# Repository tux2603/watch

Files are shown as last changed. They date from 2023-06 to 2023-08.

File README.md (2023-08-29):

# Binary Watch

_revision 2.0_

A 12 hour wrist watch that displays the current time in BCD using LEDs. The watch is powered by a single CR2032 coin cell and uses an ATtiny402 microcontroller to keep track of time and drive the LEDs. The time can be viewed or set at any time by pressing the two buttons on the face of the watch.

PCB fabrication for this project was sponsered by [PCBWay](https://www.pcbway.com/), and I would like to thank them for their support! I was very happy with the quality of the PCBs they sent me, and their staff was very easy to work with.

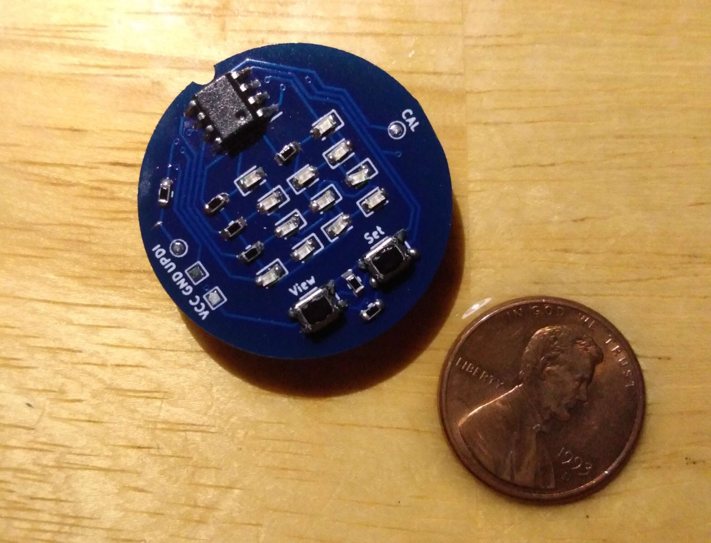
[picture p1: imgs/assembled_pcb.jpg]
Assembled PCB


_Fully assembled PCB, supplied by PCBWay and hand assembled by me. US penny for scale_

## Instructions

### Viewing the time

To view the time, simply press the `VIEW` button on the face of the watch. This will automatically wake the microcontroller and display the current time for 10 seconds. After 10 seconds, the LEDs will be turned off and the microcontroller will go back to sleep, conserving battery life.

### Setting the time

To set the time, first wake the watch from sleep by pressing the `VIEW` button. Once the watch is awake, press the `SET` button. The watch will now be in time setting mode, and the digit that is currently selected will flash once every two seconds. To change the value of the currently selected digit, press the `VIEW` button. Once the desired value is entered, press the `SET` button again to select the next digit and repeat until all digits are set. Once all digits are set, the watch will automatically return to view mode and go back to sleep after 10 seconds.

### Resetting the watch

To reset the watch, first wake the watch from sleep by pressing the `VIEW` button. Once the watch is awake, press and hold either button for at least three seconds. The watch will save the currently set time before resetting and will automatically return to view mode after the reset is complete.

## Design

Some trickery was needed to drive twelve LEDs and read two push buttons with the limited number of GPIO pins available. The LEDs are arranged in a [charlieplexing matrix](https://en.wikipedia.org/wiki/Charlieplexing), allowing all twelve LEDs to be controlled with just four tri-state GPIO pins. The push buttons are then read using a small resistor ladder with a single GPIO pin. Pressing the `VIEW` button will pull the voltage on the pin to `GND`, and pressing the `SET` button will pull the voltage on the pin to `0.5 * Vdd`. If no button is pressed, the voltage on the pin is pulled to `Vdd`. This way, only five GPIO pins are used and `PA0` is left to function solely as the UPDI pin, allowing for easy programming of the ATtiny402.

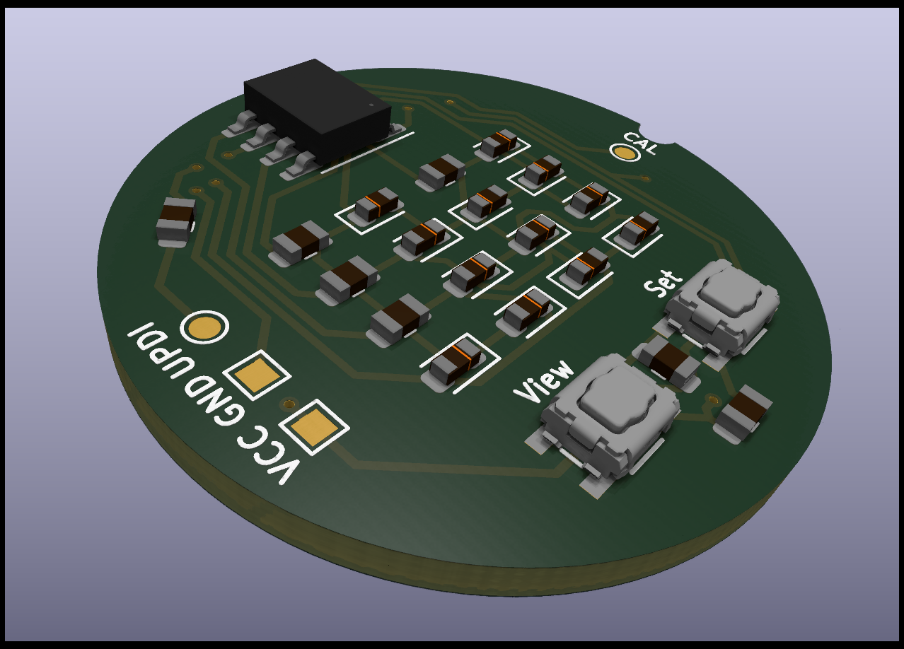
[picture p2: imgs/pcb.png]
PCB Render


### Electronics BOM

| Description | Count | Manufacturer Part Number | DigiKey Part Number  | Substitutions |
| --- | ----- | --- | --- | --- |
| CR2032 coin cell holder | 1 | BAT-HLD-001-TR | BAT-HLD-001-TRCT-ND  | Substitutions are possible, but will require traces to be re-routed |
| Blue LED | 12 | IN-S63BT5B | 1830-1068-1-ND | Any other 0603 LED can be used, but if a different color is used the color will be different |
| 47Ω 1/8W Resistor | 4 | ERJ-H3GJ470V | 10-ERJ-H3GJ470VCT-ND | Any 0603, 47Ω resistor with a power rating of 1/8W or higher |
| 4.7kΩ 1/8W Resistor | 1 | ERJ-H3GJ472V | 10-ERJ-H3GJ472VCT-ND | Any 0603, 4.7kΩ resistor with a power rating of 1/8W or higher |
| 10kΩ 1/8W Resistor | 2 | ERJ-H3GJ103V | 10-ERJ-H3GJ103VCT-ND | Any 0603, 4.7kΩ resistor with a power rating of 1/8W or higher |
| Momentary switch | 2 | EVP-AA202K | P13348SCT-ND | Substitutions are possible, but will require traces to be re-routed |
| ATtiny 402 microcontroller | 1 | ATTINY402-SSNR | ATTINY402-SSNRCT-ND  | Any ATtiny402. The ATtiny202 should also work, but has less flash and has not been tested. |

### Mechanical BOM

| Description | Count | Source |
| --- | ----- | --- |
| Watch Body | 1 | [CAD file](cad/watch-body.step) |
| Watch Back | 1 | [CAD file](cad/watch-back.step) |
| PCB | 1 | [Gerber files](pcb/gerbers.zip) |
| CR2032 coin cell | 1 | Your favorite source for watch batteries |
| 18mm watch band  | 1 | Your favorite source for watch bands |

## Assembly

### PCB

Unless you're lucky enough to have PCB fabrication facilities in house, you'll need to send the Gerber files to a third-party manufacturer for fabrication. I used DKRed for my initial prototypes, but after releasing v1 [PCBWay](https://www.pcbway.com/) reached out to me and offered to sponsor PCB fabrication for v2. Since I had selected tolerances to work with all of the major PCB fabrication services, I was more than happy to accept their offer. Having worked with both DKRed's ENIG finish and PCBWay's HASL finish, I would definietly have to say I preffered PCBWay's HASL for hand-soldering. The HASL finish made the soldering process a little bit easier, which when you're hand soldering small SMD components is always appreciated.

The components for the watch were picked to make hand soldering possible with a decent soldering iron and a steady hand, but it should also be possible to use a reflow oven or hot plate to solder the components on the face of the PCB. The battery holder will still likely need to be soldered by hand though, but it's nice and big so it shouldn't be too difficult. For hand soldering, I used the following procedure:

1.  Solder the LEDs and 47Ω resistors to the middle section of the PCB.

    - The resistors go in the spots with the two parallel silk screen lines (1, 3, 5, and 9 in Figure 1). These resistors aren't polarized, so they can be soldered in any orientation.
    - The LEDs go in the spots with the C-shaped silk screen lines around them (2, 4, 6, 7, 8, 10, 11, 12, 13, 14, 15, and 16 in Figure 1). The LEDs are polarized, so make sure to solder them in the correct orientation. If you use the LEDs specified in the BOM, the cathode will be marked with a tiny green dot. This green dot should be facing towards the C-shaped silk screen line. This orientation is also shown in Figure 1.

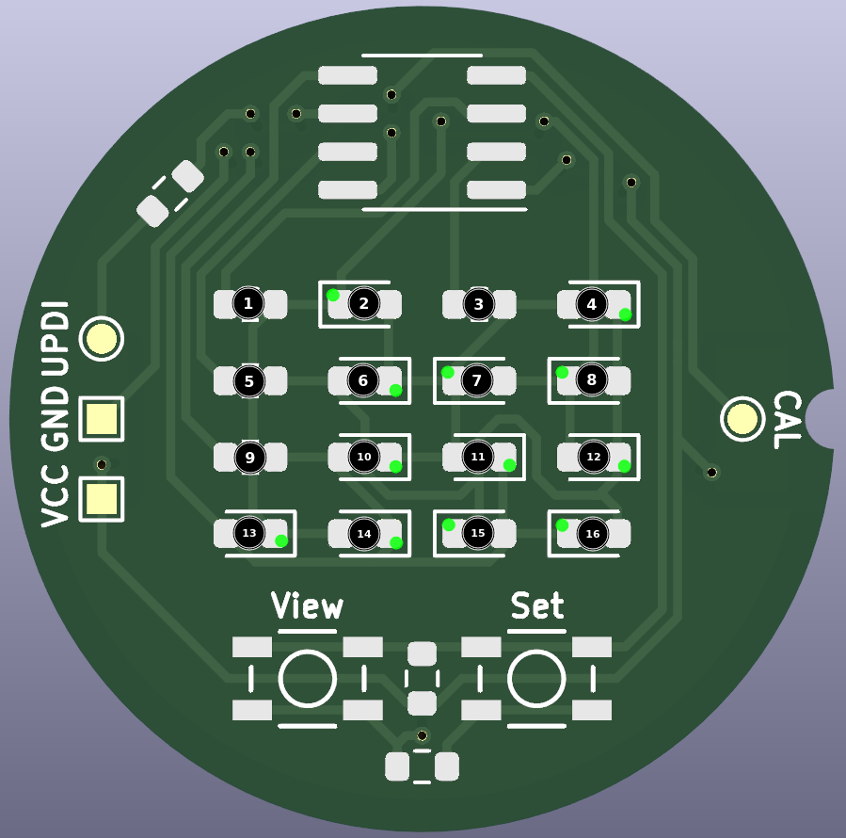
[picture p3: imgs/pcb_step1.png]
LED and resistor placement
    

    _Figure 1_: LED and resistor placement

2.  Verify that the resistors and LEDs were placed correctly

    - Apply the positive and negative connections to a 3.3V source to the pads shown in Figure 2 using the table below. If everything is soldered correctly, the corresponding

    | LED | Positive pad | Negative pad |
    | --- | ------------ | ------------ |
    | 2   | 1            | 2            |
    | 4   | 1            | 3            |
    | 6   | 3            | 1            |
    | 7   | 2            | 1            |
    | 8   | 3            | 2            |
    | 10  | 4            | 1            |
    | 11  | 1            | 4            |
    | 12  | 2            | 3            |
    | 13  | 4            | 2            |
    | 14  | 2            | 4            |
    | 15  | 4            | 3            |
    | 16  | 3            | 4            |

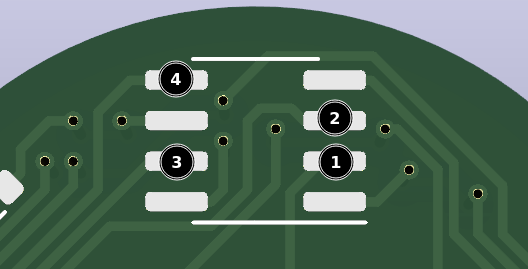
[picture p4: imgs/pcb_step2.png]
LED test pads
    

    _Figure 2_: LED test pads

3.  Solder the 4.7kΩ an 10kΩ resistors to the PCB

    - The 4.7kΩ resistor and two 10kΩ resistors go in the remaining spots with the two parallel silk screen lines (1, 2, and 3 in Figure 3). These resistors aren't polarized, so they can be soldered in any orientation.
      - The 4.7kΩ resistor goes in the spot with the two parallel silk screen lines in the upper-left corner of the PCB (1 in Figure 3)
      - The two 10kΩ resistors go in the spots with the two parallel silk screen lines in bottom center of the PCB (2 and 3 in Figure 3)

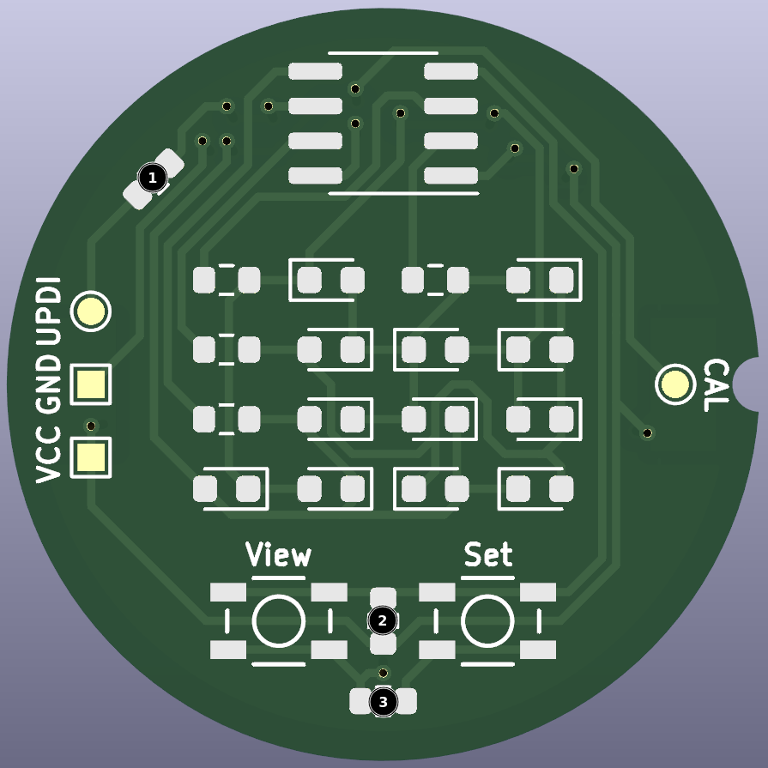
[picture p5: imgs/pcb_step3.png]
remaining resistor placement
    

    _Figure 3_: Remaining resistor placement

4.  Solder the buttons to the PCB

    - The buttons go above the silk screen labels reading `SW1` and `SW2`. The buttons aren't polarized, so they can be soldered in either direction

5.  Solder the ATtiny402 to the PCB

    - The ATtiny402 goes in the remaining spot on the front of the PCB with the small dimple or notch in the chip facing the center of the PCB

6.  Solder the battery holder to the PCB

    - Flip the PCB over and solder the battery holder to the four pads on the back

### Flashing

Three solder pads, labeled VCC, GND, and UPDI, are supplied on the watch face to allow for simple programming of the ATtiny using a UPDI programmer. Any UPDI programmer should work, but I used an Arduino Uno running [jtag2updi](https://github.com/ElTangas/jtag2updi/). The 4.7k series resistor required for flashing is already included on the PCB, so no external resistor is necessary.

1. Connect the VCC, GND, and UPDI solder pads to the corresponding pins using jumper wires. These jumper wires can be soldered or clipped on, it doesn't really matter. Note that the pads and traces are very small and fragile, so be careful not to put too much stress on them or they could rip off of the PCB.

   - The VCC pad should be connected to the 5V pin on the Arduino
   - The GND pad should be connected to the GND pin on the Arduino
   - The UPDI pad should be connected to the D6 on the Arduino

2. Hook the Arduino up to your PC and note what port it is connected to (eg, COM3, /dev/ttyACM0, /dev/ttyUSB0, etc). Set the `PORT` variable on line four of the [Makefile](Makefile) to this value, replacing the default value of `/dev/ttyACM0`

3. Run `make flash` to flash the watch. Alternatively, you can manually run the command `avrdude -c jtag2updi -P <YOUR_PORT> -p attiny402 -U flash:w:bin/main.hex -U eeprom:w:bin/eeprom.hex` to flash the watch.

4. The watch should automatically enter calibration mode after flashing. If you don't want to calibrate the watch right now, just hold down the `VIEW` button for at least three seconds to reset the watch.

### Calibration

After flashing the firmware, the watch will automatically enter one-time calibration mode. In this mode the watch will generate a square wave on the `CAL` solder pad, which can be measured using an oscilloscope. The period of this waveform should be as close to 468.75ms as possible, but it will initially be a good deal off from this value. To calibrate the watch, follow these steps:

1. Connect the `CAL` solder pad to the positive terminal of an oscilloscope probe using a jumper wire. Connect the negative terminal of the probe to the `GND` solder pad.
2. Measure the period of the generated square wave and compare it to the desired value of 468.75ms.
   - If the measured period is to high, press the `VIEW` button to decrease the period.
   - If the measured period is to low, press the `SET` button to increase the period.
3. Repeat step 2 thirteen times. After the last repetition, the watch will automatically save the calibration value and restart into standard operation mode.

To prevent accidental re-calibration, the watch will only enter calibration mode immediately after flashing by default. If you want to enable entering calibration mode without flashing the watch, write the value `0x01` to EEPROM address `0x05`. This will allow the watch to enter calibration mode by holding down the `SET` button for at least three seconds. To disable this feature again, write the value `0x00` to EEPROM address `0x05`.

## Customization

The functionality of the watch can be customized by modifying, compiling, and flashing the [source code](src/main.c). For simple changes, the following configuration options can be modified in the [config.h](src/config.h) file:

| Option | Description | Default Value | Recommended Range | Units |
| --- | --- | --- | --- | --- |
| `BLINK_FREQUENCY`  | The frequency at which the currently selected digit will blink while in time setting mode | 1 | 0.25 - 2 | Hz |
| `DEBOUNCE_COUNT` | The number of consecutive update cycles that a button state must be stable before it is considered to be pressed | 50 | 5 - 500 | update cycles |
| `RESET_HOLD_TIME`  | The number of seconds that a button must be held before the watch is reset | 3 | 1 - 10 | s |
| `SLEEP_TIMEOUT` | The number of seconds that the watch will remain awake before automatically going back to sleep | 10 | 1 - 60 | s |
| `UPDATE_FREQUENCY` | The frequency at which the LED matrix is updated and input is read from the buttons. | 480 | 96 - 5000 | Hz |

To compile the code, the avr-gcc tool chain will need to be installed with support for the ATtiny402

## License

This work is licensed under a [Creative Commons Attribution-NonCommercial 4.0 International License](https://creativecommons.org/licenses/by-nc/4.0). You are free to share, use, and modify this work for any non-commercial reasons as long as you give appropriate credit. The author grants permission for PCB and CAD design files to be sent to third-party manufacturers for fabrication as long as these fabricated parts or assemblies containing these fabricated parts are not later resold for profit.

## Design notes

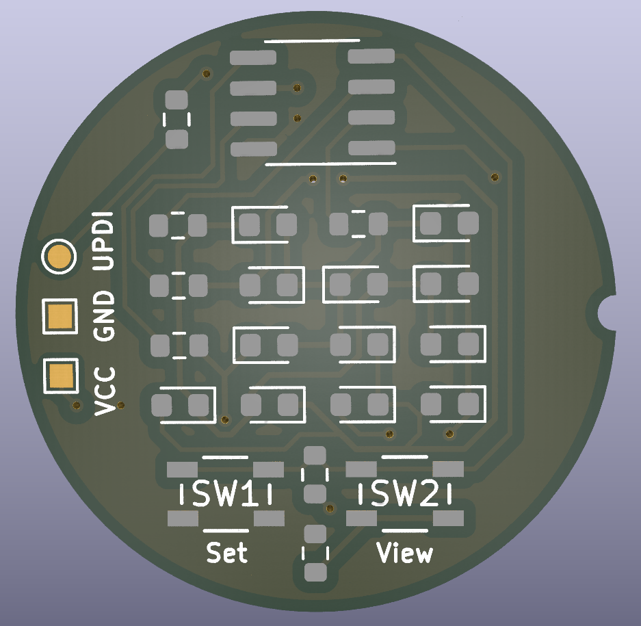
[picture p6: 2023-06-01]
imgs/pcb_front.png

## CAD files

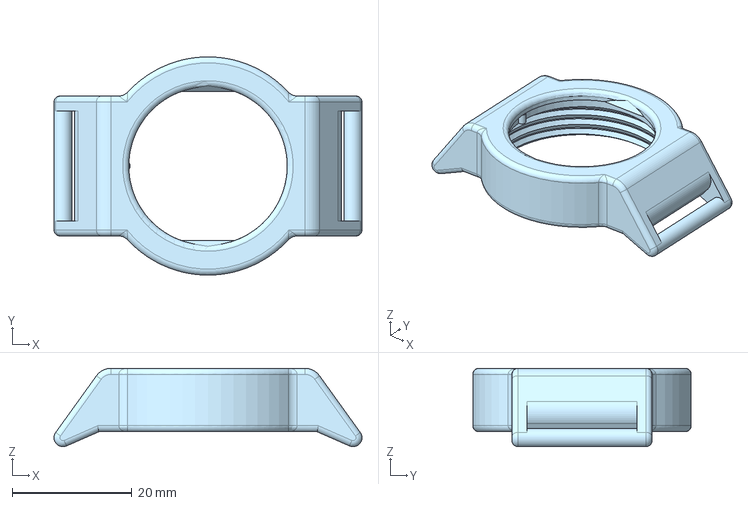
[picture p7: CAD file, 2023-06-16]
cad/watch_body.step
51.5 x 36.5 x 13.1 mm

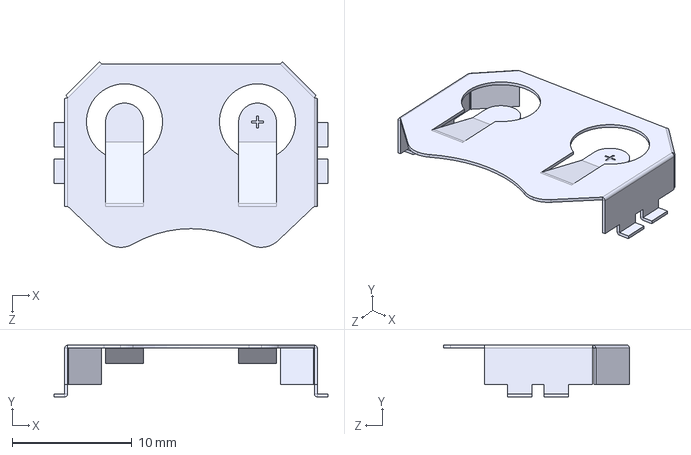
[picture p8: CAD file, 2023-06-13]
pcb/component_models/BAT-HLD-001-TR.step
22.9 x 4.32 x 15.5 mm

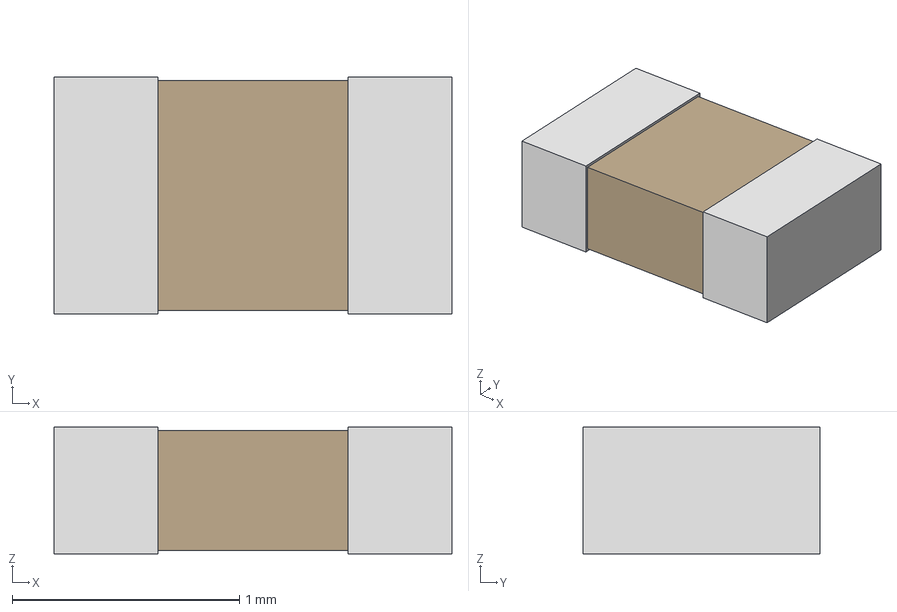
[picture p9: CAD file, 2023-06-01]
pcb/component_models/ERJ-H3GJ470V.step
1.75 x 1.04 x 0.559 mm

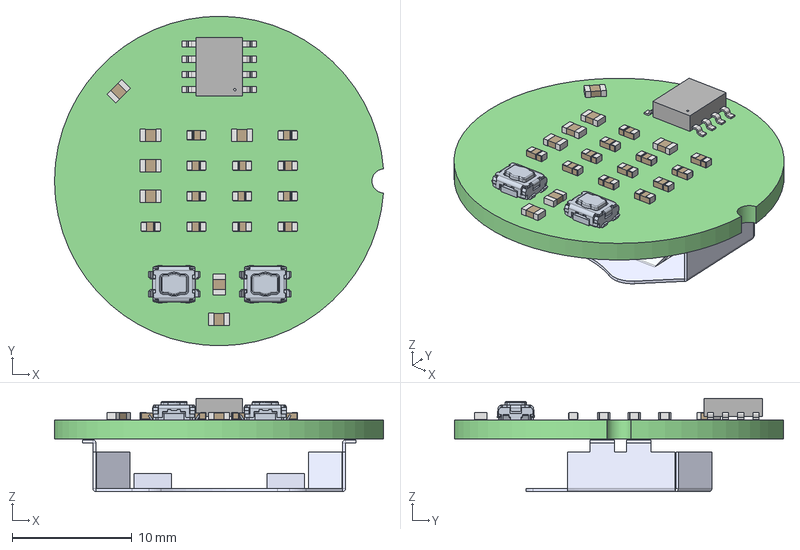
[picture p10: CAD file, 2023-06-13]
cad/pcb.step
27.5 x 27.5 x 7.77 mm
watch PCB

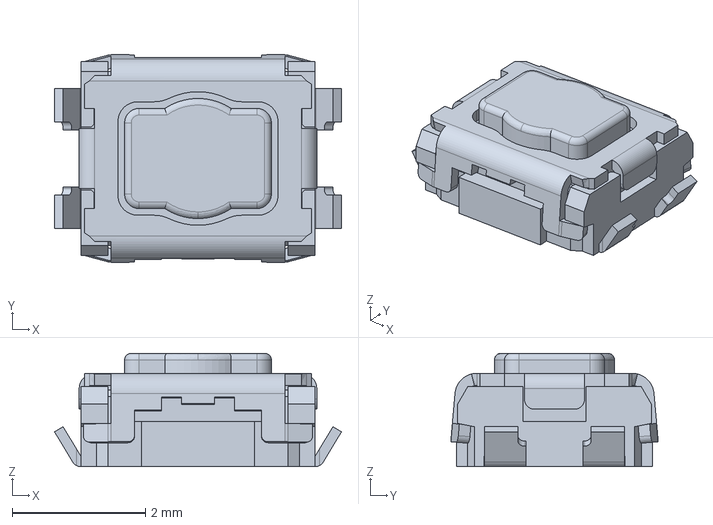
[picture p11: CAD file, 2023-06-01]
pcb/component_models/evpaa202k.step
4.30 x 3.11 x 1.70 mm

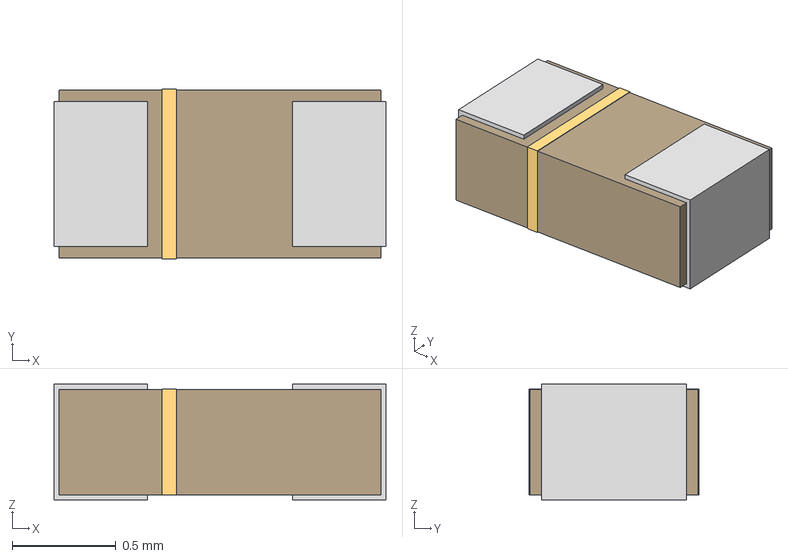
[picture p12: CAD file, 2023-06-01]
pcb/component_models/IN-S63BT.step
1.60 x 0.818 x 0.559 mm

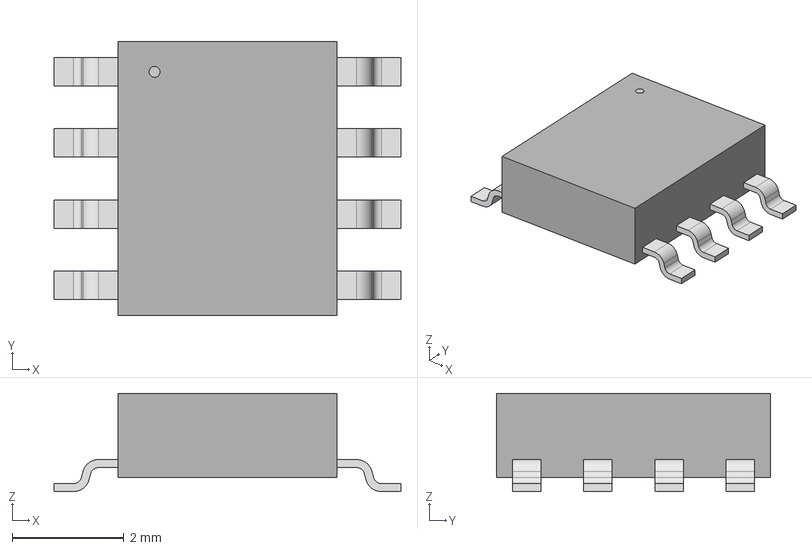
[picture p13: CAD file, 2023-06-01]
pcb/component_models/ATTINY402-SSNR.step
6.20 x 4.90 x 1.75 mm

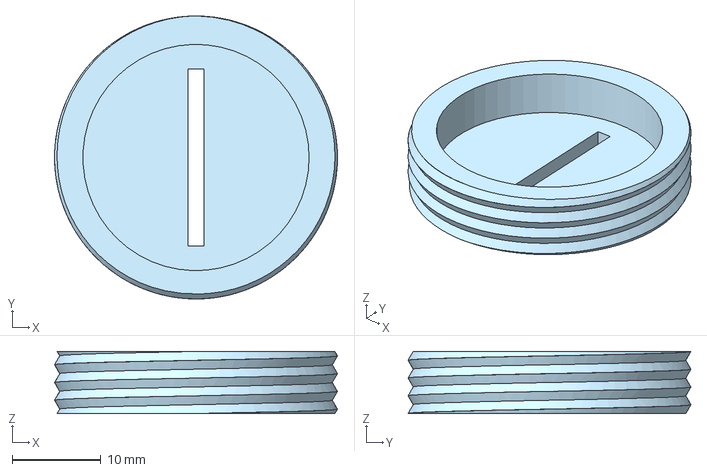
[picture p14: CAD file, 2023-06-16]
cad/watch_screw.step
31.9 x 31.9 x 7.00 mm

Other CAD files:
pcb/component_models/ERJ-H3GJ472V.step

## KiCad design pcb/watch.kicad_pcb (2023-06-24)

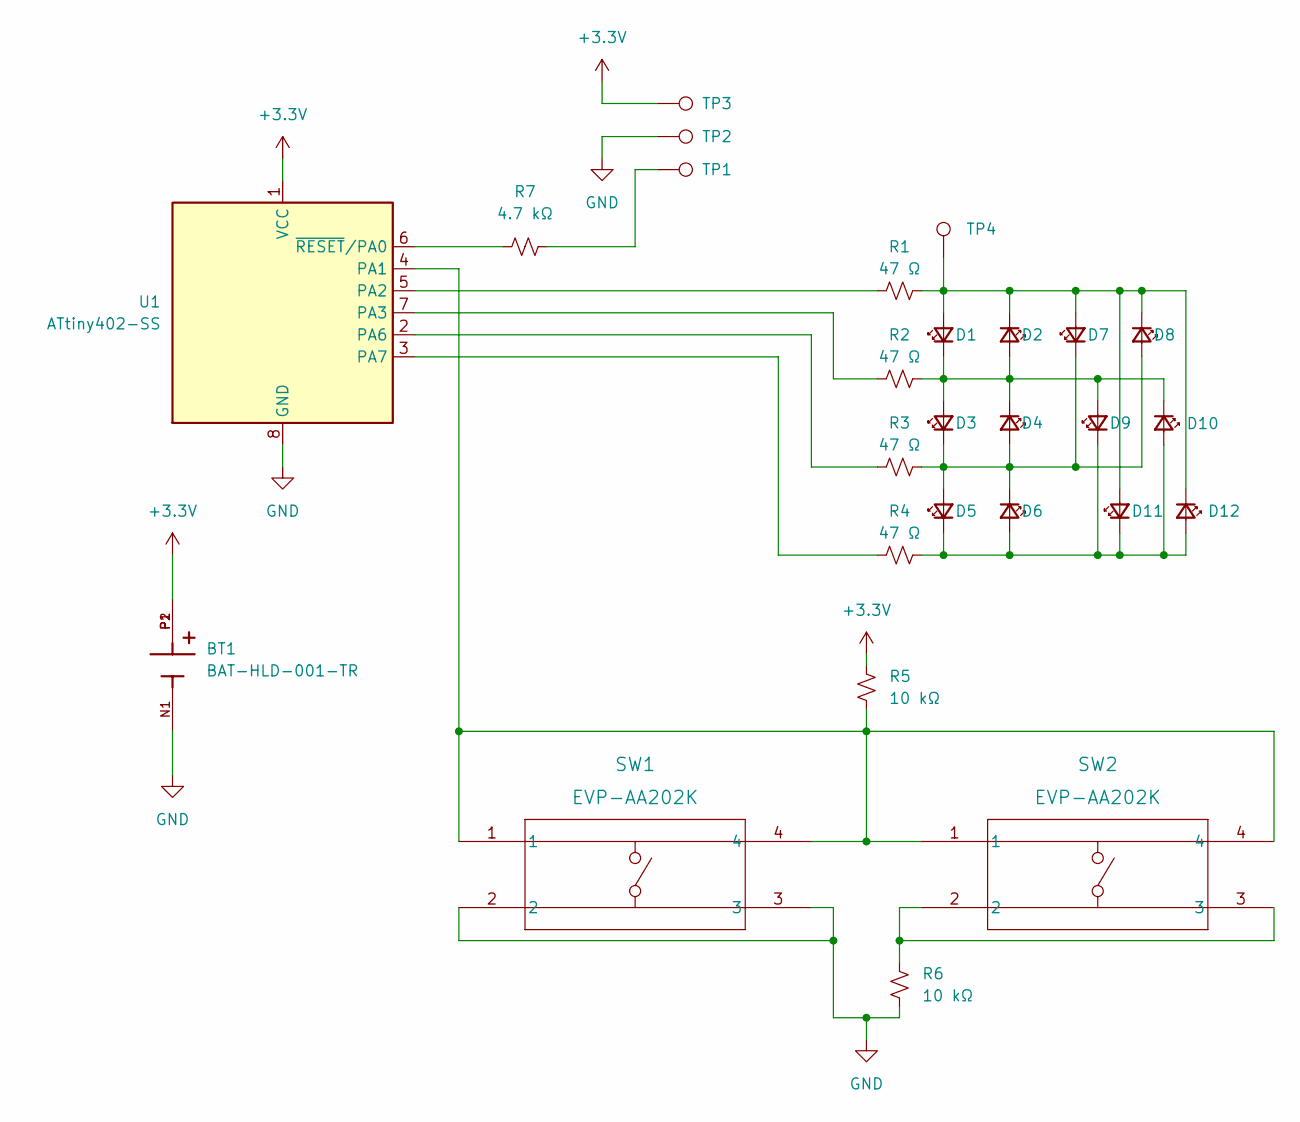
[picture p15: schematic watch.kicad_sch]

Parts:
BT1: BAT-HLD-001-TR; BAT_BAT-HLD-001-TR; PARTREV B
D1, D2, D3, D4, D5, D6, D7, D8, D9, D10, D11, D12: LED_Small; LED_0603_1608Metric
R1, R2, R3, R4: 47 Ω; R_0603_1608Metric
R5, R6: 10 kΩ; R_0603_1608Metric
R7: 4.7 kΩ; R_0603_1608Metric
SW1, SW2: EVP-AA202K; SW_EVP-AA102K_PAN
TP1, TP4: TestPoint; TestPoint_Pad_D1.0mm
TP2, TP3: TestPoint; TestPoint_Pad_1.0x1.0mm
U1: ATtiny402-SS; SOIC-8_3.9x4.9mm_P1.27mm

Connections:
+3.3V: BT1.P1, BT1.P2, R5.1, TP3.1, U1.1 (VCC)
GND: BT1.N1, R6.2, SW1.2, SW1.3, TP2.1, U1.8 (GND)
unnamed: D1.1 (K), D2.2 (A), D3.2 (A), D4.1 (K), D9.2 (A), D10.1 (K), R2.2
unnamed: D1.2 (A), D2.1 (K), D7.2 (A), D8.1 (K), D11.2 (A), D12.1 (K), R1.2, TP4.1
unnamed: D3.1 (K), D4.2 (A), D5.2 (A), D6.1 (K), D7.1 (K), D8.2 (A), R3.2
unnamed: D5.1 (K), D6.2 (A), D9.1 (K), D10.2 (A), D11.1 (K), D12.2 (A), R4.2
unnamed: R1.1, U1.5 (PA2)
unnamed: R2.1, U1.7 (PA3)
unnamed: R3.1, U1.2 (PA6)
unnamed: R4.1, U1.3 (PA7)
unnamed: R5.2, SW1.1, SW1.4, SW2.1, SW2.4, U1.4 (PA1)
unnamed: R6.1, SW2.2, SW2.3
unnamed: R7.1, U1.6 (~RESET/PA0)
unnamed: R7.2, TP1.1

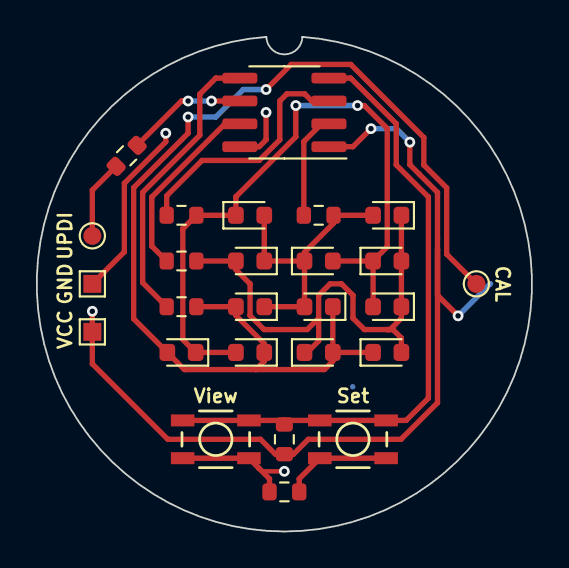
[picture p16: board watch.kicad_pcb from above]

Board: 2 copper layers, 27.5 x 27.5 mm, 27 parts (1 on the bottom side), 14 nets.

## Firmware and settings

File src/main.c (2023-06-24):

#define F_CPU 1000000

#include "config.h"
#include <avr/eeprom.h>
#include <avr/interrupt.h>
#include <avr/io.h>
#include <avr/sleep.h>
#include <stdint.h>


// ##### Pin IO masks and general constants #####

#define PA1 0x02
#define PA2 0x04
#define PA3 0x08
#define PA6 0x40
#define PA7 0x80

#define RESET_COUNT (RESET_HOLD_TIME * UPDATE_FREQUENCY)
#define SET_BTN_THRESHOLD 0xC0
#define VIEW_BTN_THRESHOLD 0x40
#define BLINK_COUNT (uint16_t)(UPDATE_FREQUENCY / (2 * BLINK_FREQUENCY))


// ##### EEPROM data addresses #####

#define EEPROM_TIME_ADDR 0x00    // Two byte address where the current time is stored while restarting
#define EEPROM_CAL_ADDR 0x02     // Two byte address where the calibrated RTC period is stored
#define EEPROM_MODE_ADDR 0x04    // One byte address to indicate which mode the device should start in
#define EEPROM_BTN_CAL_ADDR 0x05 // One byte address to indicate whether or not the device should enter calibration when the set button is held


// ##### Charlieplexing matrix data #####

// Masks for each of the BCD nibbles
#define MM_L0_MASK 0x0001
#define MM_L1_MASK 0x0002
#define MM_L2_MASK 0x0004
#define MM_L3_MASK 0x0008
#define MM_H0_MASK 0x0010
#define MM_H1_MASK 0x0020
#define MM_H2_MASK 0x0040
#define HH_L0_MASK 0x0100
#define HH_L1_MASK 0x0200
#define HH_L2_MASK 0x0400
#define HH_L3_MASK 0x0800
#define HH_H0_MASK 0x1000


#if PCB_REVISION == 1

// Pins to write high for each of the time bits
#    define MM_L0_HIGH PA3
#    define MM_L1_HIGH PA7
#    define MM_L2_HIGH PA2
#    define MM_L3_HIGH PA2
#    define MM_H0_HIGH PA2
#    define MM_H1_HIGH PA6
#    define MM_H2_HIGH PA7
#    define HH_L0_HIGH PA7
#    define HH_L1_HIGH PA6
#    define HH_L2_HIGH PA3
#    define HH_L3_HIGH PA6
#    define HH_H0_HIGH PA3

// Pins to write low for each of the time bits
#    define MM_L0_LOW PA2
#    define MM_L1_LOW PA2
#    define MM_L2_LOW PA7
#    define MM_L3_LOW PA6
#    define MM_H0_LOW PA3
#    define MM_H1_LOW PA3
#    define MM_H2_LOW PA6
#    define HH_L0_LOW PA3
#    define HH_L1_LOW PA2
#    define HH_L2_LOW PA6
#    define HH_L3_LOW PA7
#    define HH_H0_LOW PA7

#elif PCB_REVISION == 2

// Pins to write high for each of the time bits
#    define MM_L0_HIGH PA3
#    define MM_L1_HIGH PA7
#    define MM_L2_HIGH PA3
#    define MM_L3_HIGH PA6
#    define MM_H0_HIGH PA2
#    define MM_H1_HIGH PA6
#    define MM_H2_HIGH PA7
#    define HH_L0_HIGH PA7
#    define HH_L1_HIGH PA2
#    define HH_L2_HIGH PA3
#    define HH_L3_HIGH PA6
#    define HH_H0_HIGH PA2

// Pins to write low for each of the time bits
#    define MM_L0_LOW PA2
#    define MM_L1_LOW PA3
#    define MM_L2_LOW PA7
#    define MM_L3_LOW PA3
#    define MM_H0_LOW PA3
#    define MM_H1_LOW PA2
#    define MM_H2_LOW PA6
#    define HH_L0_LOW PA2
#    define HH_L1_LOW PA6
#    define HH_L2_LOW PA6
#    define HH_L3_LOW PA7
#    define HH_H0_LOW PA7

#endif



// ##### Various enums for data storage #####

// The display state simply displays the current time and waits for any button pressed.
// On entering any of the set states, the corresponding nibble is blinked on and off at 0.5Hz.
//  When the set button is pressed, the value in that nibble is incremented. When the view button
//  is pressed, the next nibble is made active for setting. Note that since hours are a bit odd,
//  HH_L and HH_H will be considered part of the same nibble for these purposes.
typedef enum {
    FSM_DISPLAY = 0x00,
    FSM_SET_HH = 0x01,
    FSM_SET_MM_H = 0x02,
    FSM_SET_MM_L = 0x03,
    FSM_BLANK = 0x04
} fsm_state_t;

typedef enum {
    LED_CHUNK_0 = 0x00,
    LED_CHUNK_1 = 0x01,
    LED_CHUNK_2 = 0x02,
    LED_CHUNK_3 = 0x03
} led_state_t;

typedef enum {
    BTN_NONE = 0x00,
    BTN_SET = 0x01,
    BTN_VIEW = 0x02
} btn_state_t;

typedef enum {
    MODE_STD = 0x00,
    MODE_CAL = 0x01
} mode_t;



// ##### LED data for smaller code size #####



const uint8_t led_high_pins[4] = {PA2, PA3, PA6, PA7};

const uint8_t led_low_pins[4][3] = {
    {PA3, PA6, PA7},
    {PA2, PA6, PA7},
    {PA2, PA3, PA7},
    {PA2, PA3, PA6}};


#if PCB_REVISION == 1

const uint16_t led_masks[4][3] = {
    {MM_H0_MASK, MM_L3_MASK, MM_L2_MASK},
    {MM_L0_MASK, HH_L2_MASK, HH_H0_MASK},
    {HH_L1_MASK, MM_H1_MASK, HH_L3_MASK},
    {MM_L1_MASK, HH_L0_MASK, MM_H2_MASK}};

const uint8_t led_blink_map[4][3] = {
    {FSM_SET_MM_H, FSM_SET_MM_L, FSM_SET_MM_L},
    {FSM_SET_MM_L, FSM_SET_HH, FSM_SET_HH},
    {FSM_SET_HH, FSM_SET_MM_H, FSM_SET_HH},
    {FSM_SET_MM_L, FSM_SET_HH, FSM_SET_MM_H}};

#elif PCB_REVISION == 2

const uint16_t led_masks[4][3] = {
    {MM_H0_MASK, HH_L1_MASK, HH_H0_MASK},
    {MM_L0_MASK, HH_L2_MASK, MM_L3_MASK},
    {MM_H1_MASK, MM_L3_MASK, HH_L3_MASK},
    {HH_L0_MASK, MM_L1_MASK, MM_H2_MASK}};

const uint8_t led_blink_map[4][3] = {
    {FSM_SET_MM_H, FSM_SET_HH, FSM_SET_HH},
    {FSM_SET_MM_L, FSM_SET_HH, FSM_SET_MM_L},
    {FSM_SET_MM_H, FSM_SET_MM_L, FSM_SET_HH},
    {FSM_SET_HH, FSM_SET_MM_L, FSM_SET_MM_H}};

#endif


// ##### Global variables #####

mode_t active_mode = MODE_STD; // The current mode of the device
uint8_t btn_cal = 0;           // Whether or not the device should enter calibration mode when the set button is held

volatile uint16_t current_bcd_time = 0x0000;          // The current time as a 16 bit BCD value, HH:MM
volatile uint16_t current_raw_time = 0x003b;          // The current time as minutes from 12:00
volatile led_state_t current_led_chunk = LED_CHUNK_0; // The current LED being lit
volatile fsm_state_t current_state = FSM_DISPLAY;     // The current state of the FSM
volatile btn_state_t last_btn_state = BTN_NONE;       // The current button state
volatile uint16_t debounce_cnt = 0;                   // The number of updates the button value has been stable
volatile uint16_t blink_cnt = 0;                      // The number of updates since the last blink
volatile uint8_t blink_state = 1;                     // The current state of the blinker
volatile uint16_t sar_step_size = 0x2000;             // The current SAR step size


// ##### Function declarations #####

/**
 * @brief Gets the current time as a 16 bit BCD value
 * 
 * @return The current time. The most significant byte is hours, and the least significant byte is minutes. 
 */
uint16_t get_time();


/**
 * @brief Increments the BCD time digits by a given amount. If the digit being
 *      incremented overflows, it will wrap around with no carry
 * 
 * @param hh The amount to increment the hours by
 * @param mm_h The amount to increment the tens digit of the minutes by
 * @param mm_l The amount to increment the ones digit of the minutes by
 * @return uint16_t The new BCD encoded time 
 */
uint16_t increment_time(uint8_t hh, uint8_t mm_h, uint8_t mm_l);


/**
 * @brief Saves the current time to EEPROM and resets the device
 * 
 */
void reset_device(mode_t reset_mode);


/**
 * @brief Initializes all registers, interrupts, etc, needed foe the watch to 
 *  function in standard operating mode
 */
void init_std();


/**
 * @brief Initializes all registers, interrupts, etc, needed foe the watch to 
 *  function in calibration mode
 */
void init_cal();



// ###########################################################################
// #####                          MAIN FUNCTION                          #####
// ###########################################################################


int main(void) {
    // The mode is stored at EEPROM_MODE_ADDR in the eeprom. This value
    //  is a 8 bit unsigned integer that is used to determine which mode
    //  the device should start in. If the value is MODE_STD, the device
    //  will start in standard operating mode. If the value is MODE_CAL,
    //  the device will start in calibration mode. If the value is anything
    //  else, the device will start in standard operating mode as a default.
    active_mode = eeprom_read_byte((uint8_t *)EEPROM_MODE_ADDR);

    if (active_mode == MODE_CAL)
        init_cal();
    else
        init_std();

    // Enable interrupts
    CPU_SREG |= CPU_I_bm;


    // Wait for the sleep bit to be set, then enter sleep mode
    for (;;) {
        while (!(SLPCTRL.CTRLA & SLPCTRL_SEN_bm)) continue;
        asm("SLEEP");
    }
}



// ###########################################################################
// #####                         INIT FUNCTIONS                          #####
// ###########################################################################


void init_std() {

    // ##### Configure clocks #####
    // OSC20M will operate in 16MHz mode. CLK_MAIN and CLK_PER will both use
    //  the correct prescaler option to hit F_CPU Hz
    CCP = CCP_IOREG_gc;                            // Allow access to protected registers
    CLKCTRL.MCLKCTRLA |= CLKCTRL_CLKSEL_OSC20M_gc; // Set the main clock to OSC20M
    CCP = CCP_IOREG_gc;                            // Allow access to protected registers
    CLKCTRL.MCLKCTRLB |= CLKCTRL_PDIV_16X_gc;      // Set the main clock prescaler to /16
    CCP = CCP_IOREG_gc;                            // Allow access to protected registers
    CLKCTRL.MCLKCTRLB |= CLKCTRL_PEN_bm;           // Enable the main clock prescaler
    CCP = CCP_IOREG_gc;                            // Allow access to protected registers
    CLKCTRL.MCLKLOCK |= CLKCTRL_LOCKEN_bm;         // Lock the main clock registers
    CCP = CCP_IOREG_gc;                            // Allow access to protected registers
    CLKCTRL.OSC32KCTRLA |= CLKCTRL_RUNSTDBY_bm;    // Enable the 32kHz oscillator in standby mode


    // ##### Load configuration data from EEPROM #####

    // Load data from EEPROM if there was a software reset
    if (RSTCTRL.RSTFR & RSTCTRL_SWRF_bm) {
        // load the data and write it to the current time
        current_raw_time = eeprom_read_word((uint16_t *)EEPROM_TIME_ADDR);

        // parse the value into the current time variable and set the state to display
        current_bcd_time = get_time();
        current_state = FSM_DISPLAY;
    }

    // If the software reset flag wasn't set, the device most likely lost power
    //  and the time wasn't saved. in this case, the FSM should start in the
    //  FSM_SET_HH state so that the user can enter the correct time
    else {
        current_state = FSM_SET_HH;
    }

    // RTC period offset is stored at EEPROM_CAL_ADDR in the eeprom. This value
    //  is a 16 bit signed integer that is added to base value of the RTC
    //  period register to help account for clock drift.
    uint16_t rtc_period = eeprom_read_word((uint16_t *)EEPROM_CAL_ADDR);

    // Once the device is calibrated, we want to prevent accidental re-calibration
    //  since the process is kind of a pain and requires access to an oscilloscope.
    //  To do this, EEPROM address EEPROM_BTN_CAL_ADDR is used to store a single
    //  byte. If this byte is set to a non-zero value, the device will enter
    //  calibration mode //  when the set button is held. If this byte is any
    //  other value, the device will just restart when the set button is held.
    btn_cal = eeprom_read_byte((uint8_t *)EEPROM_BTN_CAL_ADDR);


    // ##### Configure RTC #####
    // The RTC will trigger an overflow every minute and trigger an interrupt
    //  that will wake the device from standby if necessary and increment the
    //  raw time value
    while (RTC.STATUS & RTC_CTRLABUSY_bm) continue;         // Wait for the RTC CTRLA register to be ready to be configured
    RTC.CTRLA |= RTC_PRESCALER_DIV128_gc | RTC_RUNSTDBY_bm; // Set the RTC prescaler to 128 and enable it in standby mode
    RTC.CLKSEL |= RTC_CLKSEL_INT32K_gc;                     // Set the RTC clock source to the 32kHz oscillator
    while (RTC.STATUS & RTC_PERBUSY_bm) continue;           // Wait for the RTC PER register to be ready to be configured
    RTC.PER = rtc_period;                                   // Set the RTC period to the calibrated value
    RTC.INTCTRL |= RTC_OVF_bm;                              // Enable the RTC overflow interrupt
    while (RTC.STATUS & RTC_CTRLABUSY_bm) continue;         // Wait for the RTC CTRLA register to be ready to be configured
    RTC.CTRLA |= RTC_RTCEN_bm;                              // Enable the RTC


    // ##### Configure CPUINT #####
    // TODO: The window comparison doesn't seem to be working
    // Five interrupts will be used:
    //  - TCA overflow will trigger the device to enter standby, and has the highest priority
    //  - TCB overflow will trigger the LEDs to update
    //  - ADC conversion will trigger the FSM to update
    //  - ADC window will reset the TCA CNT register to 0
    //  - A low level on PA1 will trigger the device to wake up
    CCP = CCP_IOREG_gc;                 // Allow access to protected registers
    CPUINT.CTRLA |= CPUINT_LVL0RR_bm;   // Enable round-robin scheduling
    CPUINT.LVL1VEC = TCA0_OVF_vect_num; // Set the TCA overflow interrupt to priority level 1


    // ##### Configure EVSYS #####
    // When TCB overflows, and event will be generated that will trigger the ADC to begin a conversion
    EVSYS.SYNCCH0 = EVSYS_SYNCCH0_TCB0_gc;          // Set the TCB overflow event to trigger sync channel 0
    EVSYS.ASYNCUSER1 = EVSYS_ASYNCUSER9_SYNCCH0_gc; // Set the ADC to be triggered by sync channel 0


    // ##### Configure TCA #####
    // TCA0 will trigger the device to enter sleep mode after SLEEP_TIMEOUT seconds of inactivity
    TCA0.SINGLE.CTRLA |= TCA_SINGLE_CLKSEL_DIV1024_gc;    // Set the TCA clock source to CLK_PER/1024
    TCA0.SINGLE.CTRLB |= TCA_SINGLE_WGMODE_NORMAL_gc;     // Set the TCA waveform generation mode to normal
    TCA0.SINGLE.INTCTRL |= TCA_SINGLE_OVF_bm;             // Enable the TCA overflow interrupt
    TCA0.SINGLE.PER = (SLEEP_TIMEOUT * F_CPU) / 1024 - 1; // Set the TCA period to SLEEP_TIMEOUT seconds
    TCA0.SINGLE.CNT = 0x0000;                             // Set the TCA count to 0
    TCA0.SINGLE.CTRLA |= TCA_SINGLE_ENABLE_bm;            // Enable the TCA


    // ##### Configure TCB #####
    // TCB will trigger the LED update interrupt at UPDATE_FREQUENCY Hz
    TCB0.INTCTRL |= TCB_CAPT_bm;              // Enable the TCB capture interrupt
    TCB0.CCMP = F_CPU / UPDATE_FREQUENCY - 1; // Set TCB's compare value to trigger at UPDATE_FREQUENCY Hz
    TCB0.CTRLA |= TCB_ENABLE_bm;              // Set the TCB clock source to TCA, and enable the TCB


    // ##### Configure ADC #####
    // The device doesn't need the full resolution, so use 8-bit mode
    // The ADC will be triggered by TCB, and will trigger an interrupt when the conversion is complete
    // The ADC will trigger another interrupt when the voltage falls below 0.75*Vdd
    ADC0.CTRLA |= ADC_RESSEL_8BIT_gc;   // Set the ADC resolution to 8-bit
    ADC0.CTRLC |= ADC_REFSEL0_bm;       // Set the ADC to use Vdd as reference
    ADC0.CTRLC |= ADC_PRESC_DIV8_gc;    // Set the ADC clock prescaler to CLK_PER/8, or 1MHz/8 = 125kHz
    ADC0.CTRLD |= ADC_INITDLY_DLY32_gc; // Set the ADC sampling delay to 32 CLK_ADC cycles after enabling
    ADC0.CTRLE |= ADC_WINCM_BELOW_gc;   // Set the ADC window mode to below
    ADC0.MUXPOS |= ADC_MUXPOS_AIN1_gc;  // Set the ADC input to PA1
    ADC0.EVCTRL |= ADC_STARTEI_bm;      // Set the ADC to be triggered by the event system
    ADC0.WINLT = SET_BTN_THRESHOLD;     // Set the ADC window comparator low threshold to ~0.75*Vdd
    ADC0.INTCTRL |= ADC_RESRDY_bm;      // Enable the ADC result ready interrupt
    ADC0.INTCTRL |= ADC_WCMP_bm;        // Enable the ADC window comparator interrupt
    ADC0.CTRLA |= ADC_ENABLE_bm;        // Enable the ADC


    // ##### Configure PORTA #####
    // The default state of all pins will be inputs with pull-ups disabled. PA2, PA3, PA6, and PA7
    //  are used to charlieplex a matrix of 12 LEDs, and will be toggled to digital outputs
    //  as appropriate in a timed interrupt.:hat is triggered on a low level.
    PORTA.DIRCLR = PA2 | PA3 | PA6 | PA7; // Set LED pins to inputs
    PORTA.DIRCLR = PA1;                   // Set the switch pin to an input
}
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

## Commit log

2023-05-24 Add initial PCB files
    [BK-916-TR.step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]
2023-05-25 Remember to enable ADC and better defines
2023-05-25 Get the interrupt vector names right
2023-05-26 Add interrupts
2023-05-26 Reconfigure pcb constraints for DKRed
2023-06-01 Add alignment notch to PCB
    [watch.kicad_pcb]
2023-06-01 Add step files for watch case
    [watch_body.step, watch_screw.step]
2023-06-01 Add 3D component models Also fix silk screen and add rendered image of PCB
    [ATTINY402-SSNR.step, BK-916-TR.step, ERJ-H3GJ470V.step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]
2023-06-01 Move cad files to a more appropriate folder name
    [pcb.step, watch_back.step, watch_body.step]
2023-06-01 Update gerber files
    [watch-B_Cu.gbr, watch-B_Mask.gbr, watch-B_Paste.gbr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]
2023-06-08 Fix bugs, working release Reset currently doesn't work, but we didn't need that anyway
    [main.c]
2023-06-10 Increase LED brightness by ~3x
2023-06-10 Fix view and set silkscreen labels
    [watch-B_Cu.gbr, watch-B_Mask.gbr, watch-B_Paste.gbr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]
2023-06-11 Make the PCB more aesthetically pleasing
    [watch-B_Cu.gbr, watch-B_Mask.gbr, watch-B_Paste.gbr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]
2023-06-12 Add simple clock calibration
2023-06-12 Nudge silkscreen labels off of the traces
    [watch.kicad_pcb]
2023-06-13 EEPROM flag to prevent accidental recalibration
    [main.c]
2023-06-13 Use a CR2032 instead of a CR1216
    [BAT-HLD-001-TR.step, BK-916-TR.step, pcb.step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]
2023-06-13 Add alignment dots to PCB image
2023-06-16 Modify PCB to work with more fabrication services Also rotate the alignment pin
    [watch.kicad_pcb, watch_body.step, watch_screw.step]
2023-06-24 Fix wrong LEDs blinking for v1 PCB
    [main.c]
2023-06-24 Minor PCB tweaks
    [watch.kicad_pcb]
2023-08-29 Add image of assembled PCB
2023-08-29 Add thanks for PCBWay sponsorshi[
